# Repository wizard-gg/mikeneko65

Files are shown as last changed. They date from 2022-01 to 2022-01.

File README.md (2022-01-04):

# Mikeneko 65 V3

A simple 65% keyboard for DIYers. This project was derived from [kkatano's Bakeneko 65](https://github.com/kkatano/bakeneko-65).

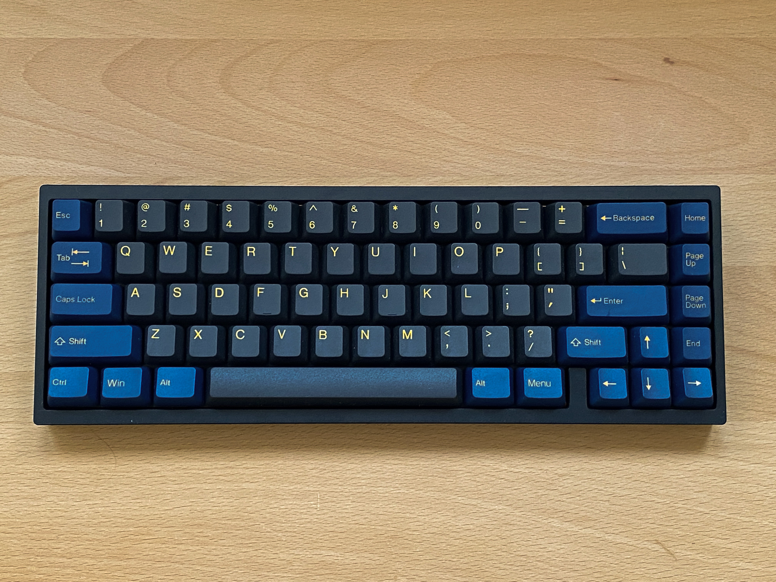
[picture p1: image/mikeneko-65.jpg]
Mikeneko 65


## Differences between Mikeneko 65 and Bakeneko 65

- Added support for PCB screw ins stabilizer
- Changed MCU to ATmega32U4-MU(R) to cope with MCU supply shortage

## Features

- Single piece tray case
- O-ring gasket mount (Friction fit)
- [Unified Daughterboard](https://github.com/ai03-2725/Unified-Daughterboard) or [Simplified Daughterboard](https://github.com/kb-elmo/simplified-daughterboard)
- QMK firmware and VIA (For now, you can use Bakeneko 65's firmware as is)
- PCB designed with KiCAD 5.1.4

## Layouts

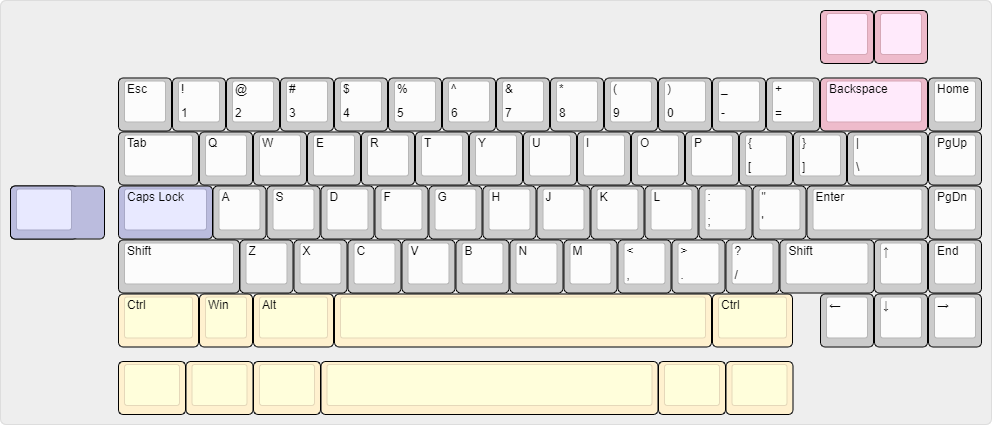
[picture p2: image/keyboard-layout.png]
Mikeneko 65 layouts


## Specs

- Dimensions: 315 x 110 x 30mm
- Front height: 18.5mm
- Home row height: 31mm(with GMK keycaps and bumpons)
- Typing angle: 6 degree
- Weight:
  - PLA Case: 390g
  - Aluminum Case: 760g
- O-ring gasket: VMQ-50(Silicone 50 duro) AS568-264

## Notes

- All files are to be used at your own risk
- As for stabilizers, both PCB snap ins and screw ins are supported

## Resources

- Documents: https://drive.google.com/drive/folders/1tddSihOS8Pgf1lTQOjHohYCl8efxXIeH
  - For now, you can refer Bakeneko 65's documents as is
  - Parts guide and other useful information
- Discord: https://discord.com/channels/927936241805189171/
  - Have fun with community members
  - Talk about Mikeneko builds and mods, and share your works
  - You can also contact me from there

## Special thanks to

- **kkatano** Open-sourced Bakeneko 65 and answered my questions in his community
- People who supported the development of Bakeneko series

## Also I should mention
- Many keyboard community members for giving me advice and feedback, thanks!

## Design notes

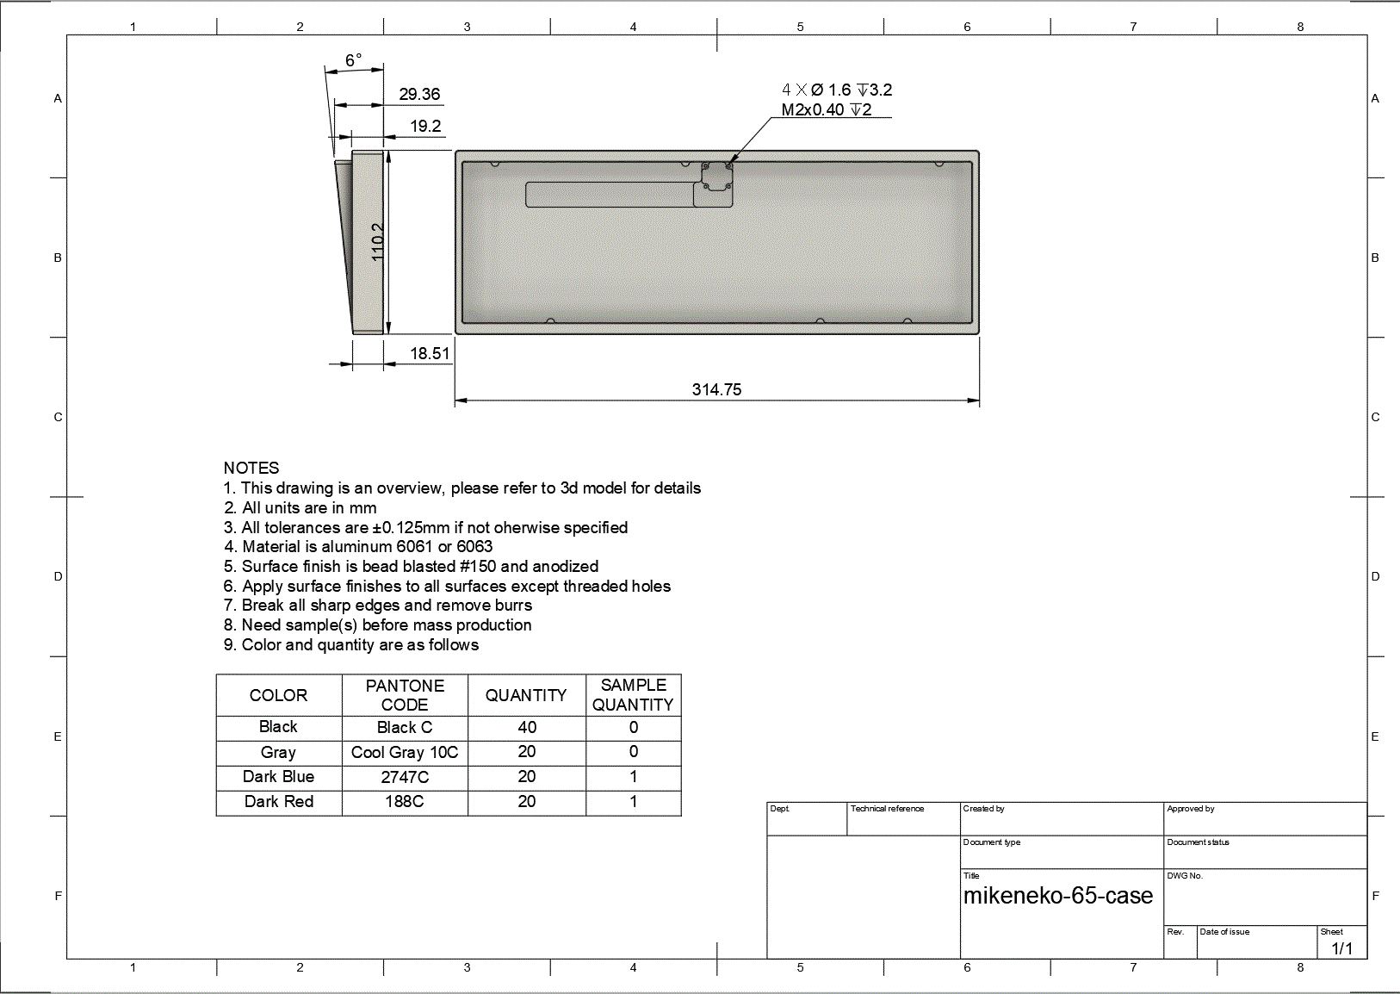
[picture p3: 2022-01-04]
case/mikeneko-65-case-details-for-quotation.gif

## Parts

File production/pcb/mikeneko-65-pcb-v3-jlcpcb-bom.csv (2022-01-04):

Designator | Comment | Footprint | LCSC Part #
C1 C2 C3 | 0.1u | Capacitor_SMD:C_0805_2012Metric | C49678
C4 | 10u | Capacitor_SMD:C_0805_2012Metric | C15850
C5 C6 | 22p | Capacitor_SMD:C_0805_2012Metric | C1804
C7 | 1u | Capacitor_SMD:C_0805_2012Metric | C28323
D68 D67 D66 D65 D64 D63 D62 D61 D60 D59 D58 D57 D56 D55 D54 D53 D52 D51 D50 D49 D48 D47 D46 D45 D44 D43 D42 D41 D40 D39 D38 D37 D36 D35 D34 D33 D32 D31 D30 D29 D28 D27 D26 D25 D24 D23 D22 D21 D20 D19 D18 D17 D16 D15 D14 D13 D12 D11 D10 D9 D8 D7 D6 D5 D4 D3 D2 D1 | 1N4148 | Diode_SMD:D_SOD-123 | C81598
F1 | 500mA | Fuse:Fuse_1206_3216Metric | C70076
J1 | JST SH 4-pin | Connector_JST:JST_SH_SM04B-SRSS-TB_1x04-1MP_P1.00mm_Horizontal | C160404
R1 R4 | 10k | Resistor_SMD:R_0805_2012Metric | C17414
R2 R3 | 22 | Resistor_SMD:R_0805_2012Metric | C17561
SW1 | Reset | Button_Switch_SMD:SW_SPST_TL3342 | C318884
U1 | SRV05-4 | Package_TO_SOT_SMD:SOT-23-6 | C85364
U2 | ATmega32U4-MU | Package_DFN_QFN:QFN-44-1EP_7x7mm_P0.5mm_EP5.2x5.2mm | C45874
Y1 | 16MHz | Crystal:Crystal_SMD_3225-4Pin_3.2x2.5mm | C13738

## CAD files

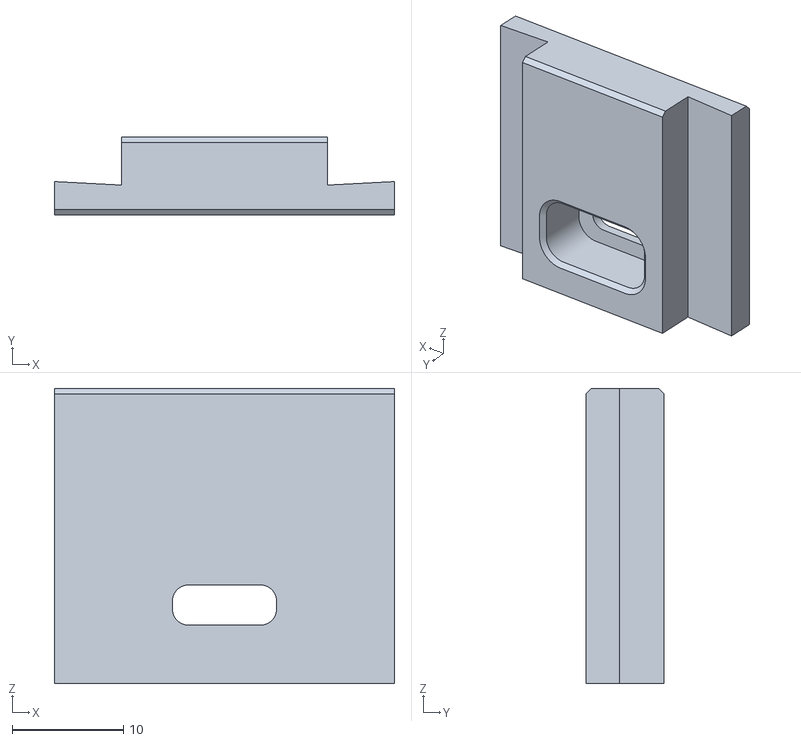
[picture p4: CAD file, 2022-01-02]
case-pla/mikeneko-65-pla-split-usb.stl
30.5 x 7.00 x 26.5

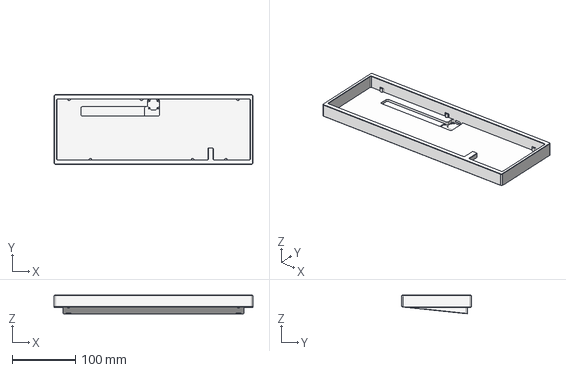
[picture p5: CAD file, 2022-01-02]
case/mikeneko-65-case.step
314.8 x 110.2 x 29.4 mm

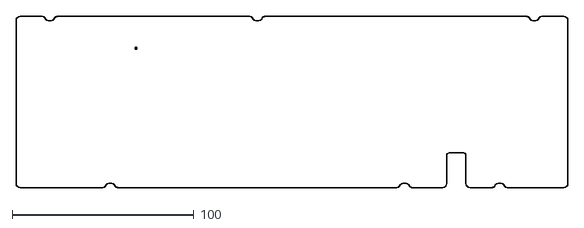
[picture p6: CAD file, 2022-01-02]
pcb/pcb-outline.dxf
303.8 x 94.2

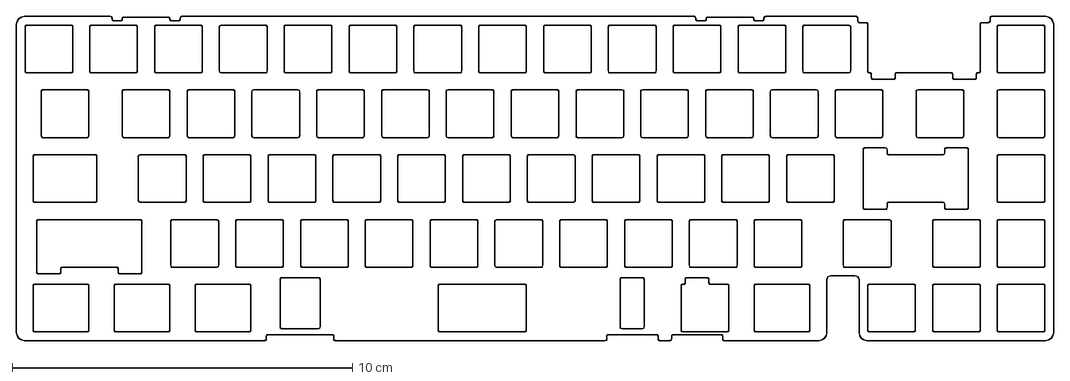
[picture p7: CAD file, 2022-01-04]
plate/mikeneko-65-plate.dxf
30.5 x 9.53 cm

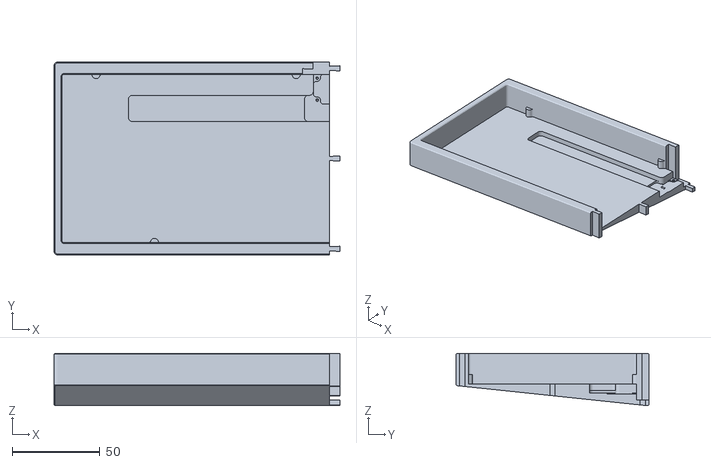
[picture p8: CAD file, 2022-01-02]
case-pla/mikeneko-65-pla-split-left.stl
163.4 x 110.2 x 30.0

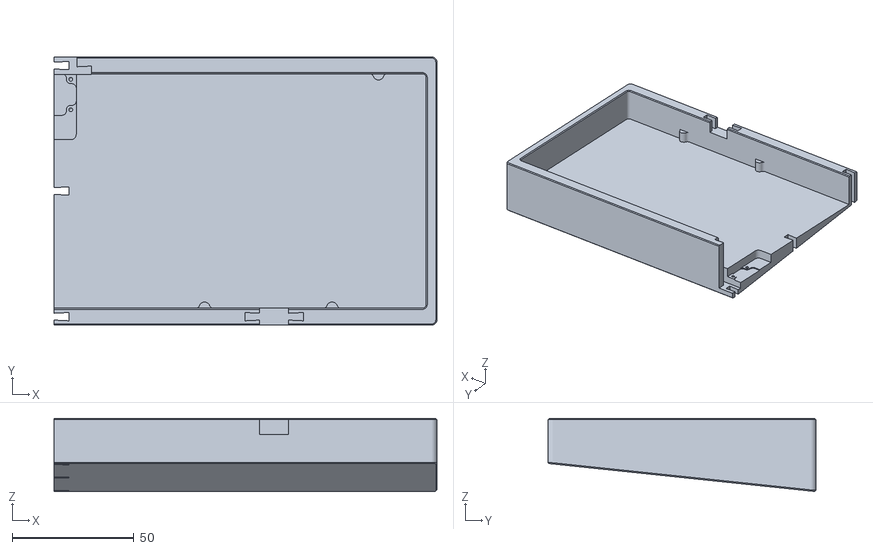
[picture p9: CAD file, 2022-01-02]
case-pla/mikeneko-65-pla-split-right.stl
157.3 x 110.2 x 30.0

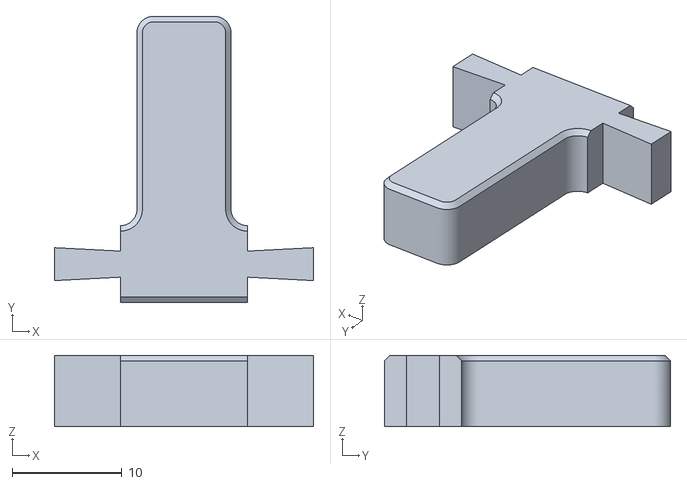
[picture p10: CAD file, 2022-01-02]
case-pla/mikeneko-65-pla-split-blocker.stl
23.6 x 26.1 x 6.50

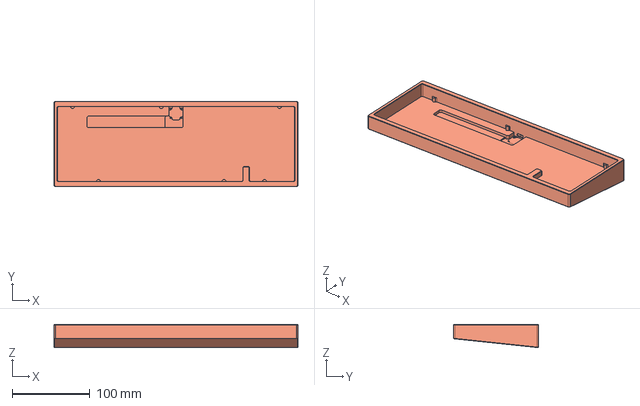
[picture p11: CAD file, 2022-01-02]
case-pla/mikeneko-65-pla.step
314.8 x 110.2 x 30.0 mm

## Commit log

2022-01-02 bakeneko-65のdevelopブランチの20220102のコードをコミット。
    [bakeneko-65-case.step, bakeneko-65-fr4-plate.kicad_pcb, bakeneko-65-fr4-plate.sch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]
2022-01-02 .gitignoreを追加。
2022-01-02 bakenekoをmikenekoに変換。
    [matrix.sch, mikeneko-65-case.step, mikeneko-65-fr4-plate.kicad_pcb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]
2022-01-02 回路図のmcuをatmega32u4-muに変更。
    [mikeneko-65-pcb.sch]
2022-01-02 回路図から基板を更新。
    [mikeneko-65-pcb.kicad_pcb]
2022-01-02 atmega32u4-muの配線を修正。 配線の太さの定義を追加、配線間隔の最小値を0.127mmに変更
    [mikeneko-65-pcb.kicad_pcb]
2022-01-04 pcbのgerberファイルとbomファイルとcplファイルを更新。
    [mikeneko-65-pcb-v3-jlcpcb-bom.csv, mikeneko-65-pcb.kicad_pcb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]
2022-01-04 見積もり用の図面(画像)ファイルを追加。 既存の図面(PDF)ファイルを削除。
2022-01-04 スクリューインタイプのスタビライザーに対応し、ガーバーファイルを更新。
    [mikeneko-65-fr4-plate.kicad_pcb, mikeneko-65-plate.dxf]
2022-01-04 ドキュメントを更新。
2022-01-05 キーボードの画像を更新。
2022-01-05 不要なファイルを削除。
2022-01-12 著作権表示を整理。
